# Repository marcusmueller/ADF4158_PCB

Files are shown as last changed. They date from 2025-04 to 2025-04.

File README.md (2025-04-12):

# ADF4158 + HMC391 PCB

This project is a PCB that contains an
[ADF4158](https://www.analog.com/en/products/adf4158.html) direct
modulation/waveform generating fractional-N frequency synthesizer and a
[HMC391](https://www.analog.com/en/products/hmc391.html) 3.9 - 4.45 GHz VCO. The
board is primarily intended as an LO source for a 10 GHz FMCW radar inspired by
the
[ADALM-PHASER](https://wiki.analog.com/resources/eval/user-guides/circuits-from-the-lab/cn0566/overview_setup). The
VCO output can be used with a subharmonic mixer and an IF around 1.6 GHz to
cover the 10 - 10.5 GHz amateur radio band.

The board runs from a 12 - 16 VDC supply, exposes all the control pins of the
ADF4158 in a 2.58 mm pin header (3.3V logic) and includes an optional 10 MHz
reference input. The BOM cost is around 45€.

The PLL loop filter has been design with
[ADIsimPLL](https://www.analog.com/en/lp/resources/adisimpll.html). The design
file is [ADF4158_HMC391.pll](ADF4158_HMC391.pll).

PCB top 3D render

## Outputs

Outputs for the latest commit in the `main` branch are built by CI and published
to Github pages. Additionally, outputs for each commit are published as a Github
artifact.

- [Schematic PDF](https://daniestevez.github.io/ADF4158_PCB/schematic.pdf)
- [PCB PDF](https://daniestevez.github.io/ADF4158_PCB/pcb.pdf)
- [Gerbers](https://daniestevez.github.io/ADF4158_PCB/gerbers.zip)
- [ERC report](https://daniestevez.github.io/ADF4158_PCB/erc.rpt)
- [DRC report](https://daniestevez.github.io/ADF4158_PCB/drc.rpt)
- [PCB top 3D render](https://daniestevez.github.io/ADF4158_PCB/pcb-top.png)
- [PCB bottom 3D render](https://daniestevez.github.io/ADF4158_PCB/pcb-bottom.png)

## BOM

The BOM for this project is available as a
[DigiKey list](https://www.digikey.es/en/mylists/list/G0QI1PQN03).

## PCB fabrication

The PCB is intended to be fabricated on [JLCPCB](https://jlcpcb.com/) using the
following options:

- Base material: FR-4
- Layers: 2
- Deburring/Edge rounding: Yes
- PCB thickness: 0.6 mm (50 ohm RF traces are designed for this stack up)
- Surface finish: LeadFree HASL (HASL with lead is not available with 0.6 mm PCB)
- Min via hole size/diamager: 0.3 mm (0.4/0.45 mm)

These options are very inexpensive: $5.80 for qty. 5, $9.00 for qty. 30.

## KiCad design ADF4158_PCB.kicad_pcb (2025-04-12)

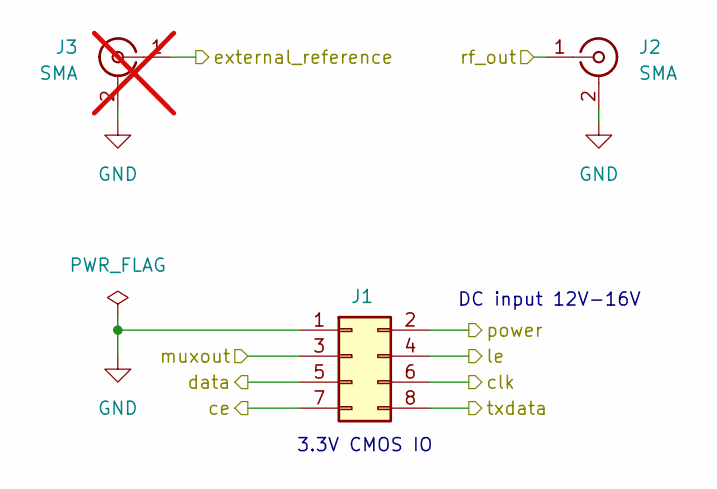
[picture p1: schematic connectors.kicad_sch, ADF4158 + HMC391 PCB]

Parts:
J1: Conn_02x04_Odd_Even; PinHeader_2x04_P2.54mm_Vertical; Digikey Part Number 2057-PH2-08-UA-ND
J2: SMA; WRL-23187; Digikey Part Number 1568-WRL-23187-ND
J3: SMA; WRL-23187; Digikey Part Number 1568-WRL-23187-ND; not fitted

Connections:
/ADF4158 + HMC391/ce: J1.7; also elsewhere on the board
/ADF4158 + HMC391/clk: J1.6; also elsewhere on the board
/ADF4158 + HMC391/data: J1.5; also elsewhere on the board
/ADF4158 + HMC391/external_reference: J3.1 (In); also elsewhere on the board
/ADF4158 + HMC391/le: J1.4; also elsewhere on the board
/ADF4158 + HMC391/txdata: J1.8; also elsewhere on the board
/Connectors/power: J1.2; also elsewhere on the board
/muxout: J1.3; also elsewhere on the board
/rf_out: J2.1 (In); also elsewhere on the board
GND: J1.1, J2.2 (Ext), J3.2 (Ext); also elsewhere on the board

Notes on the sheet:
DC input 12V-16V
3.3V CMOS IO

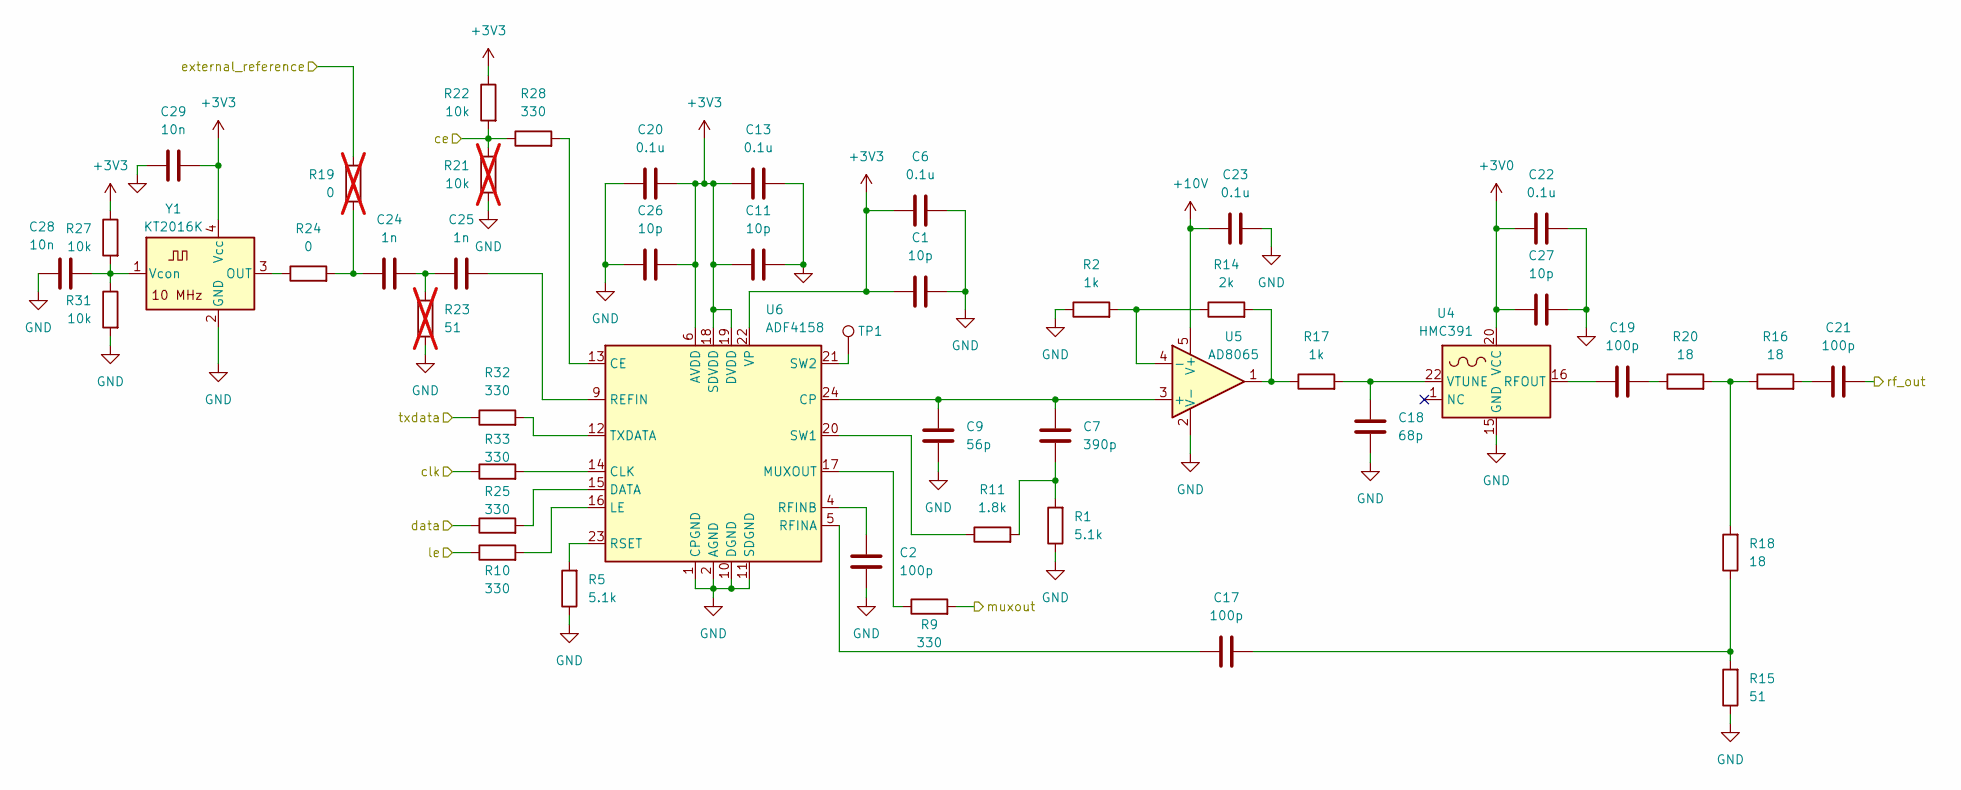
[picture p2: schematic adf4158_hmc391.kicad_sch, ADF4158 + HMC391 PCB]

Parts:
C1, C11, C26, C27: 10p; C_0402_1005Metric; Digikey Part Number 1276-1139-1-ND
C2, C17, C19, C21: 100p; C_0402_1005Metric; Digikey Part Number 1276-1025-1-ND
C6, C13, C20, C22, C23: 0.1u; C_0402_1005Metric; Digikey Part Number 1276-1002-1-ND
C7: 390p; C_0402_1005Metric; Digikey Part Number 490-1296-1-ND
C9: 56p; C_0402_1005Metric; Digikey Part Number 490-1288-1-ND
C18: 68p; C_0402_1005Metric; Digikey Part Number 490-5876-1-ND
C24, C25: 1n; C_0402_1005Metric; Digikey Part Number 1276-1032-1-ND
C28, C29: 10n; C_0402_1005Metric; Digikey Part Number 1276-1028-1-ND
R1, R5: 5.1k; R_0402_1005Metric; Digikey Part Number P5.1KDCCT-ND
R2, R17: 1k; R_0402_1005Metric; Digikey Part Number P1.00KLCT-ND
R9, R10, R25, R28, R32, R33: 330; R_0402_1005Metric; Digikey Part Number P330LCT-ND
R11: 1.8k; R_0402_1005Metric; Digikey Part Number P1.80KLCT-ND
R14: 2k; R_0402_1005Metric; Digikey Part Number P2.00KLCT-ND
R15: 51; R_0402_1005Metric; Digikey Part Number P51.0LCT-ND
R16, R18, R20: 18; R_0402_1005Metric; Digikey Part Number P18.0LCT-ND
R19: 0; R_0402_1005Metric; Digikey Part Number P0.0JCT-ND; not fitted
R21: 10k; R_0402_1005Metric; Digikey Part Number P10.0KLCT-ND; not fitted
R22, R27, R31: 10k; R_0402_1005Metric; Digikey Part Number P10.0KLCT-ND
R23: 51; R_0402_1005Metric; Digikey Part Number P51.0LCT-ND; not fitted
R24: 0; R_0402_1005Metric; Digikey Part Number P0.0JCT-ND
TP1: TestPoint; TestPoint_Pad_D2.0mm
U4: HMC391; QFN-24-1EP_4x4mm_P0.5mm_EP2.8x2.8mm; Digikey Part Number 505-HMC391LP4ECT-ND
U5: AD8065; TSOT-23-5; Digikey Part Number AD8065ARTZ-REELCT-ND
U6: ADF4158; LFCSP-24-1EP_4x4mm_P0.5mm_EP2.5x2.5mm; Digikey Part Number 505-ADF4158CCPZ-ND
Y1: KT2016K; Digikey Part Number 478-KT2016K10000ZAW33ZGKCT-ND

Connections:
+3V0: C22.2, C27.2, U4.20 (VCC); also elsewhere on the board
+3V3: C1.2, C6.2, C11.2, C13.2, C20.2, C26.2, C29.1, R22.1, R27.1, U6.6 (AVDD), U6.7 (AVDD), U6.8 (AVDD), U6.18 (SDVDD), U6.19 (DVDD), U6.22 (VP), Y1.4 (Vcc); also elsewhere on the board
+10V: C23.2, U5.5 (V+); also elsewhere on the board
/ADF4158 + HMC391/ce: R21.1, R22.2, R28.1; also elsewhere on the board
/ADF4158 + HMC391/clk: R33.1; also elsewhere on the board
/ADF4158 + HMC391/data: R25.1; also elsewhere on the board
/ADF4158 + HMC391/external_reference: R19.2; also elsewhere on the board
/ADF4158 + HMC391/le: R10.1; also elsewhere on the board
/ADF4158 + HMC391/txdata: R32.1; also elsewhere on the board
/muxout: R9.2; also elsewhere on the board
/rf_out: C21.2; also elsewhere on the board
GND: C1.1, C2.2, C6.1, C9.2, C11.1, C13.1, C18.2, C20.1, C22.1, C23.1, C26.1, C27.1, C28.1, C29.2, R1.1, R2.1, R5.1, R15.1, R21.2, R23.1, R31.2, U4.15 (GND), U4.25 (GND), U5.2 (V-), U6.1 (CPGND), U6.2 (AGND), U6.3 (AGND), U6.10 (DGND), U6.11 (SDGND), U6.25 (AGND), Y1.2 (GND); also elsewhere on the board
unnamed: C7.2, R1.2, R11.2
unnamed: C17.2, R15.2, R18.1
unnamed: C19.2, R20.1
unnamed: C21.1, R16.2
unnamed: C24.1, R19.1, R24.2
unnamed: C24.2, C25.1, R23.2
unnamed: R14.2, R17.1, U5.1
unnamed: R16.1, R18.2, R20.2
unnamed: C19.1, U4.16 (RFOUT)
unnamed: C18.1, R17.2, U4.22 (VTUNE)
unnamed: C7.1, C9.1, U5.3 (+), U6.24 (CP)
unnamed: R2.2, R14.1, U5.4 (-)
unnamed: R28.2, U6.13 (CE)
unnamed: R33.2, U6.14 (CLK)
unnamed: R25.2, U6.15 (DATA)
unnamed: R10.2, U6.16 (LE)
unnamed: R9.1, U6.17 (MUXOUT)
unnamed: C25.2, U6.9 (REFIN)
unnamed: C17.1, U6.5 (RFINA)
unnamed: C2.1, U6.4 (RFINB)
unnamed: R5.2, U6.23 (RSET)
unnamed: R11.1, U6.20 (SW1)
unnamed: TP1.1, U6.21 (SW2)
unnamed: R32.2, U6.12 (TXDATA)
unnamed: R24.1, Y1.3 (OUT)
unnamed: C28.2, R27.2, R31.1, Y1.1 (Vcon)

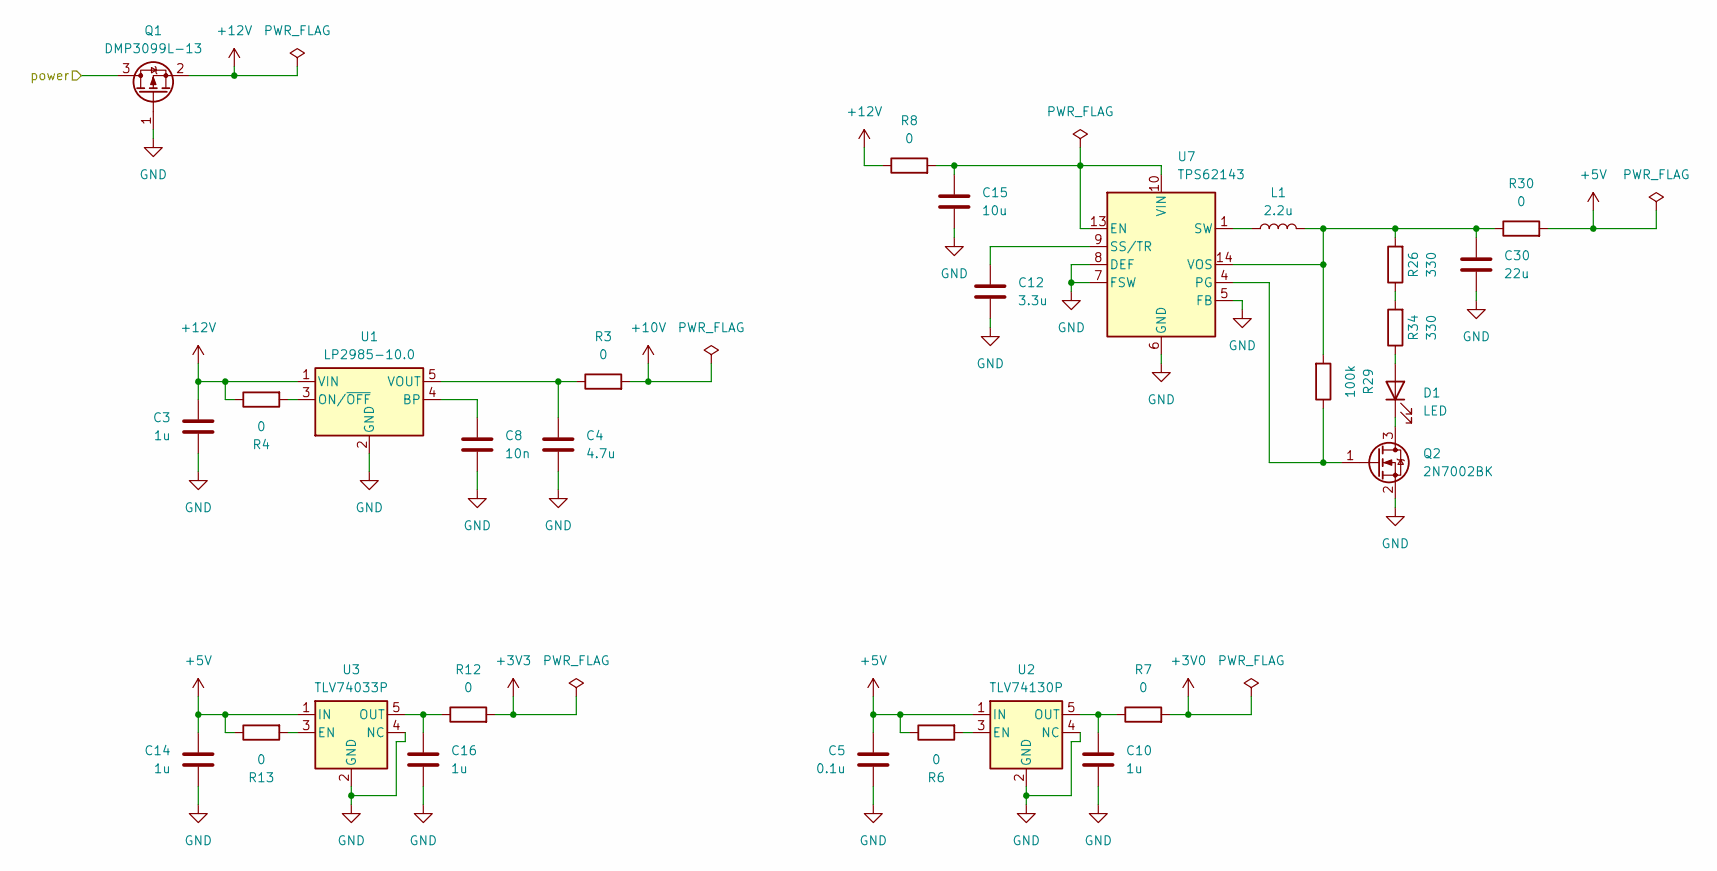
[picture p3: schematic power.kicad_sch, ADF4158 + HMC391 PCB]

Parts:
C3, C10, C14, C16: 1u; C_0603_1608Metric; Digikey Part Number 1276-1184-1-ND
C4: 4.7u; C_0805_2012Metric; Digikey Part Number 490-GRM21BR71C475ME51KCT-ND
C5: 0.1u; C_0402_1005Metric; Digikey Part Number 1276-1002-1-ND
C8: 10n; C_0402_1005Metric; Digikey Part Number 1276-1028-1-ND
C12: 3.3u; C_1206_3216Metric; Digikey Part Number 1276-1841-1-ND
C15: 10u; C_0805_2012Metric; Digikey Part Number 1276-2872-1-ND
C30: 22u; C_0603_1608Metric; Digikey Part Number 1276-1274-1-ND
D1: LED; LED_0603_1608Metric; Digikey Part Number 3147-B1931NG--20D001114U1930CT-ND
L1: 2.2u; L_1008_2520Metric; Digikey Part Number 490-10649-1-ND
Q1: DMP3099L-13; SOT-23-3; Digikey Part Number DMP3099L-13DICT-ND
Q2: 2N7002BK; SOT-23; Digikey Part Number 1727-4789-1-ND
R3, R4, R6, R7, R8, R12, R13, R30: 0; R_0402_1005Metric; Digikey Part Number P0.0JCT-ND
R26, R34: 330; R_0402_1005Metric; Digikey Part Number P330LCT-ND
R29: 100k; R_0402_1005Metric; Digikey Part Number P100KLCT-ND
U1: LP2985-10.0; SOT-23-5; Digikey Part Number 296-24263-1-ND
U2: TLV74130P; SOT-23-5; Digikey Part Number 296-50000-1-ND
U3: TLV74033P; SOT-23-5; Digikey Part Number 296-TLV74033PDBVRCT-ND
U7: TPS62143; VQFN-16-1EP_3x3mm_P0.5mm_EP1.68x1.68mm_ThermalVias; Digikey Part Number 296-39448-1-ND

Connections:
+3V0: R7.2; also elsewhere on the board
+3V3: R12.2; also elsewhere on the board
+5V: C5.1, C14.1, R6.1, R13.1, R30.2, U2.1 (IN), U3.1 (IN)
+10V: R3.2; also elsewhere on the board
+12V: C3.1, Q1.2 (S), R4.1, R8.1, U1.1 (VIN)
/Connectors/power: Q1.3 (D); also elsewhere on the board
GND: C3.2, C4.2, C5.2, C8.2, C10.2, C12.2, C14.2, C15.2, C16.2, C30.2, Q1.1 (G), Q2.2 (S), U1.2 (GND), U2.2 (GND), U2.4 (NC), U3.2 (GND), U3.4 (NC), U7.5 (FB), U7.6 (GND), U7.7 (FSW), U7.8 (DEF), U7.15 (GND), U7.16 (GND), U7.17 (GND); also elsewhere on the board
unnamed: D1.2 (A), R34.1
unnamed: D1.1 (K), Q2.3 (D)
unnamed: L1.1, U7.1 (SW), U7.2 (SW), U7.3 (SW)
unnamed: Q2.1 (G), R29.1, U7.4 (PG)
unnamed: R26.1, R34.2
unnamed: C8.1, U1.4 (BP)
unnamed: R4.2, U1.3 (ON/~OFF)
unnamed: C4.1, R3.1, U1.5 (VOUT)
unnamed: R6.2, U2.3 (EN)
unnamed: C10.1, R7.1, U2.5 (OUT)
unnamed: R13.2, U3.3 (EN)
unnamed: C16.1, R12.1, U3.5 (OUT)
unnamed: C15.1, R8.2, U7.10 (VIN), U7.11 (VIN), U7.12 (VIN), U7.13 (EN)
unnamed: C12.1, U7.9 (SS/TR)
unnamed: C30.1, L1.2, R26.2, R29.2, R30.1, U7.14 (VOS)

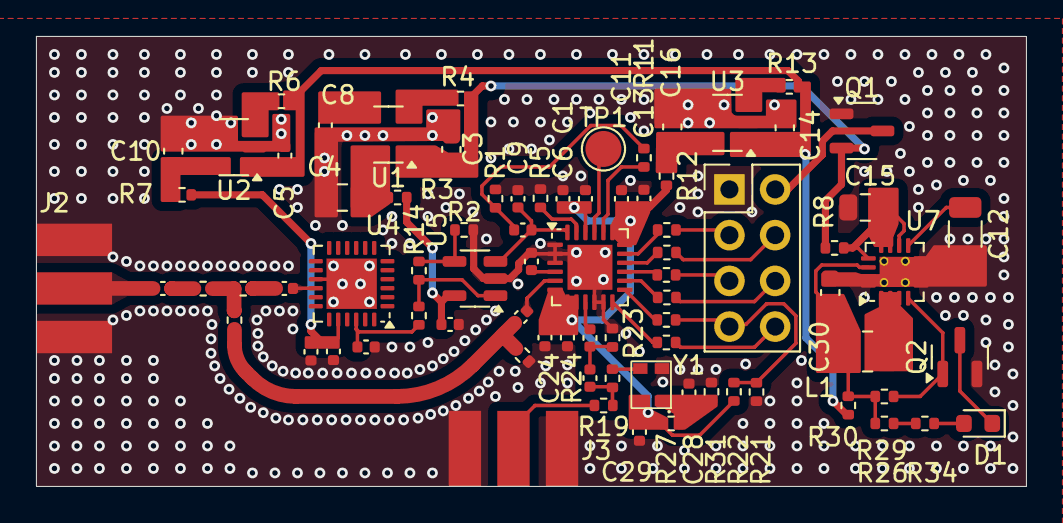
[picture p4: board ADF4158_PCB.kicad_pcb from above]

Board: 2 copper layers, 55.0 x 25.0 mm, 80 parts (0 on the bottom side), 56 nets.

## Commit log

2025-04-12 add kicad project files
    [ADF4158_PCB.kicad_pcb, ADF4158_PCB.kicad_sch, adf4158_hmc391.kicad_sch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]
2025-04-12 increase PCB render zoom
    Increase PCB render zoom to remove larger margin in the PNG file.
2025-04-12 add PLL loop filter design file
